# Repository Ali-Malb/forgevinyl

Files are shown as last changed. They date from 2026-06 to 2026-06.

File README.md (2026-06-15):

I'm creating a magnetic interactive "turntable" station for my fridge. Put a custom mini 3D printed/acrylic vinyl record (representing a favourite album) on the station, it reads a custom embedded NFC/RFID tag, flashes a custom coloured LED sequence mirroring the album's aesthetics and automatically plays the top track from its built-in MP3 module and speaker.

## 📊 Bill of Materials (BOM)

| Part Name | Qty | Description | Component/Purchase Link |
| :--- | :---: | :--- | :--- |
| **Seeed Studio XIAO RP2040** | 1 | Main microcontroller board (Pre-soldered headers) | [Amazon India](https://www.amazon.in) |
| **DFPlayer Mini MP3 Module** | 1 | Audio decoding hardware with integrated amplifier | [Amazon India](https://www.amazon.in) |
| **MFRC522 RFID Module Kit** | 1 | 13.56 MHz RF sensor module + SPI peripheral pins | [Amazon India](https://www.amazon.in) |
| **INVENTO 2040 Micro Speaker** | 1 | 4Ω 2W Slim rectangular laptop cavity speaker | [Amazon India](https://www.amazon.in) |
| **1k Ohm Resistor** | 1 | Axial THT resistor for DFPlayer RX line noise suppression | [Amazon India](https://www.amazon.in) |
| **Custom 2-Layer PCB** | 1 | Custom KiCad-designed motherboard layout | [JLCPCB Fabrication](https://jlcpcb.com) |
| **N35 12x2mm Neodymium Magnets** | 4 | Heavy-duty disc magnets for fridge-mounting the case | [Amazon India](https://www.amazon.in) |
| **NTAG213 NFC Stickers (25mm)** | 10 | 13.56 MHz ISO 14443A tags embedded inside vinyl discs | [Amazon India](https://www.amazon.in) |
| **3M Heavy Duty Double-Sided Tape** | 1 | 19mm transparent foam adhesive to mount the 2040 speaker | [Amazon India](https://www.amazon.in) |
| **Custom 3D Enclosure & Lid** | 1 | 3D-printed casing body and snap-fit rear closure plate | [Local 3D Print File](casing/) |




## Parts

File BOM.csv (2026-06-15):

Reference | Qty | Value | DNP | Exclude from BOM | Exclude from Board | Footprint | Datasheet | Part Description / Source
J1 | 1 | Seeed Studio XIAO RP2040 |  |  |  | Connector_PinHeader_2.54mm:PinHeader_1x08_P2.54mm_Vertical | ~ | Seeed Studio XIAO RP2040 (Pre-Soldered)
J2 | 1 | MFRC522 RFID Module (SPI) |  |  |  | Connector_PinHeader_2.54mm:PinHeader_1x03_P2.54mm_Vertical | ~ | ApTechDeals RC522 RF IC Card Sensor Module Kit
J3 | 1 | INVENTO 2040 Speaker |  |  |  | Connector_PinHeader_2.54mm:PinHeader_1x02_P2.54mm_Vertical | ~ | INVENTO 2040 4ohm 2W Micro Cavity Laptop Speaker
J4 | 1 | DFPlayer Mini (Pins 1-8) |  |  |  | Package_DIP:DIP-16_W7.62mm | ~ | DFPlayer Mini MP3 Player Module (Left Pin Side)
J5 | 1 | DFPlayer Mini (Pins 9-16) |  |  |  | Package_DIP:DIP-14_W7.62mm | ~ | DFPlayer Mini MP3 Player Module (Right Pin Side)
R1 | 1 | 1k Ohm |  |  |  | Resistor_THT:R_Axial_DIN0207_L6.3mm_D2.5mm_P7.62mm_Horizontal | ~ | 1kΩ Resistor (For DFPlayer RX Line Noise Suppression)
CASE | 1 | Custom Enclosure Shell |  | Yes | Yes | ~ | ~ | 3D Printed Casing (24mm x 126.6mm x 73.8mm)
LID | 1 | Enclosure Back Plate |  | Yes | Yes | ~ | ~ | 3D Printed Back Panel Lid with Magnet Insets
MAG1-MAG4 | 4 | N35 12x2mm Magnet |  | Yes | Yes | ~ | ~ | SNOOGG 12x2mm Neodymium Disc Rare Earth Magnets
TAGS | 10 | NTAG213 NFC Sticker |  | Yes | Yes | ~ | ~ | RapidRadio 13.56 MHz ISO 14443A NFC Type 2 Stickers (25mm)
TAPE | 1 | Double-Sided Tape |  | Yes | Yes | ~ | ~ | Scotch 3M Heavy Duty Clear Double-Sided Foam Tape (19mm)

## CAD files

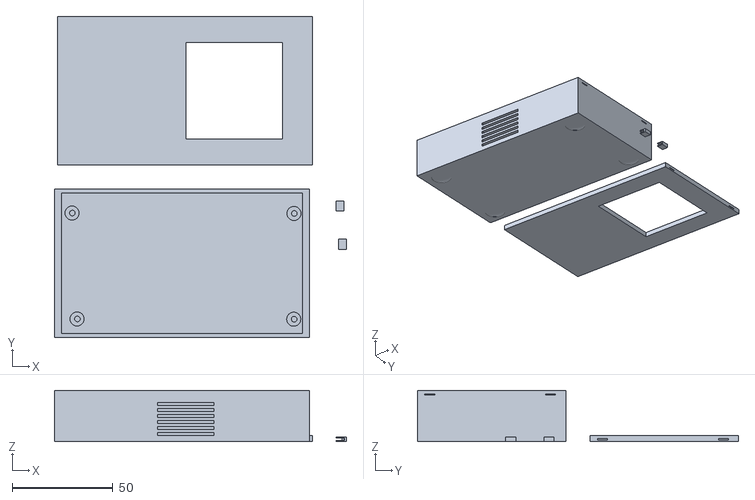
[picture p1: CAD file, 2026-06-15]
3D file- Vinyl Player case.stl
145.0 x 159.6 x 25.4

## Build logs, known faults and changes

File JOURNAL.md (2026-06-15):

I'm creating a magnetic interactive "turntable" station for my fridge. Put a custom mini 3D printed/acrylic vinyl record (representing a favourite album) on the station, it reads a custom embedded NFC/RFID tag, flashes a custom coloured LED sequence mirroring the album's aesthetics and automatically plays the top track from its built-in MP3 module and speaker. I just finished designing  the pcb and I'm excited to make tha casing. time: 3 hours



I won't lie, it took way longer than I would have liked to complete the case design due to the fact that fitting everything into a 24mm box that wasn't meant to be modified was a headache. I spent hours and hours trying to get the side-wall speaker grille slots lined up just right. Then, I spent a lot of time figuring out how to make four very exact screw holes to attach the speaker and found those plastic screw pillars would take up too much space and would probably make the case rattle anyway. I had to abandon that part and redo it for a very simple tape-on/ tiny alignment rails setup. It was hard to get the exact windows for the USB-C port and MicroSD slot right, to measure the back magnet pockets without ruining the front RFID paper window, but it's done and ready to be 3D printed!

time: 4 hours

Closed (with pcb)

no pcb- 
Open (top)

open (bottom)


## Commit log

2026-06-14 Add journal entry for finishing the PCB
2026-06-15 Document case design process and time spent
    Added details about the case design challenges and time spent on the project.
